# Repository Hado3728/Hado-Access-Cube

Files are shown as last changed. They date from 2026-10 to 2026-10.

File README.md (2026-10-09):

# HADO Edge Access Cube

A modular, 3D-printable enclosure and hardware architecture for a touchless, AI-powered access control terminal. Built for the IIITB-Qualcomm-Arduino COMET Hackathon.

\---

## Overview

The **HADO Edge Access Cube** combines dual-brain compute (Qualcomm QRB2210 Linux MPU + STM32U585 Real-Time MCU) with multi-modal sensing (MIPI Camera, Time-of-Flight depth sensing, and PN532 NFC) inside a compact $115 \\times 115 \\times 42\\text{ mm}$ 3-piece modular shell.

This repository contains the CAD models, AI prompt generation assets, bill of materials (BOM), and mechanical specifications required to manufacture, assemble, and deploy the physical device.

**WEBSITE
https://thunderous-marzipan-0d5d81.netlify.app/**
---

\---

## Mechanical Architecture

The enclosure uses a 3-piece snap-and-screw modular structure designed for FDM/SLA 3D printing and brass heat-set inserts.

```text
+-----------------------------------------------------------------+
| Part 1: Front Bezel \& Display Faceplate                         |
|   - Holds 4.3" COF Display, Camera, ToF Sensor, Mic, \& Speaker  |
+-----------------------------------------------------------------+
                                |  (Interlocking Lip + M2.5 Screws)
                                v
+-----------------------------------------------------------------+
| Part 2: Main Body Housing \& Chassis                             |
|   - Houses Qualcomm Arduino UNO Q MPU/MCU Stack \& NFC Rail      |
+-----------------------------------------------------------------+
                                |  (Flush Shoulder + M2.5 Screws)
                                v
+-----------------------------------------------------------------+
| Part 3: Rear Wall-Mounting Backplate                            |
|   - Features Keyhole Wall Mounts \& Cable Pass-Through Window    |
+-----------------------------------------------------------------+
```

### Key Enclosure Specs

* **Footprint:** $115\\text{ mm} \\times 115\\text{ mm} \\times 42\\text{ mm}$
* **Wall Thickness:** $2.5\\text{ mm}$ minimum structural wall thickness
* **Fasteners:** M2.5 and M3 brass heat-set inserts with countersunk machine screws
* **Materials Recommended:** PETG or ABS/ASA (25–30% Gyroid infill, 0.2mm layer height)

\---

## Hardware Stack \& Bill of Materials (BOM)

|Subsystem|Component|Interface / Notes|
|-|-|-|
|**Compute**|Qualcomm® Arduino® UNO™ Q|QRB2210 MPU + STM32U585 MCU|
|**Display**|Evelta 4.3" COF Non-Touch LCD (*DMG48270F043\_01WN*)|UART / TTL ($105.5 \\times 67.2 \\times 3.0\\text{ mm}$)|
|**Perception**|1080p MIPI-CSI RGB Camera Module|MIPI-CSI Ribbon Cable|
|**Depth / Proximity**|VL53L1X Time-of-Flight (ToF) Sensor|$\\text{I}^2\\text{C}$ Bus|
|**Contactless**|PN532 NFC Reader Board|$\\text{I}^2\\text{C}$ / SPI (Internal slide rail)|
|**Audio**|INMP441 MEMS Mic + 3W Speaker \& PAM8403 Amp|$\\text{I}^2\\text{S}$ \& PWM|
|**Power**|12V to 5V/3A DC-DC Buck Converter PMU|Terminal Block / USB-C|

\---

## Repository Structure

```text
├── cad/
│   ├── step/                 # STEP files for SolidWorks/Fusion 360 editing
│   ├── stl/                  # 3D printable STL files for slicers
│   └── prompts/              # Coordinate-mapped AI Text-to-CAD prompts (Parts 1-3)
├── docs/
│   ├── schematics/           # Wiring and interconnect diagrams
│   └── mechanics/            # Exploded assembly blueprints \& clearances
├── BOM                       # Complete hardware component list
├── LICENSE                   # MIT License
└── README.md                 # Project documentation
```

\---

## Assembly Instructions

1. **Insert Brass Heat-Sets:**

   * Press four **M2.5 brass heat-set inserts** into the corner bosses of **Part 1 (Front Bezel)** using a soldering iron.
   * Press four **M3 brass heat-set inserts** into the mainboard standoff pillars of **Part 2 (Main Housing)**.
2. **Mount Front Sensors \& Screen:**

   * Snap the Evelta 4.3" screen into the internal rear seat of Part 1.
   * Press-fit the MIPI camera and ToF sensor into their respective alignment sleeves.
3. **Install Core Compute \& NFC:**

   * Slide the PN532 NFC module into the top ceiling rail channel of Part 2 until the detent locks.
   * Secure the Qualcomm Arduino UNO Q board onto the M3 standoffs using M3x6mm screws.
4. **Final Closure:**

   * Join Part 1 and Part 2 via the perimeter interlocking lip.
   * Attach Part 3 to the rear shoulder and secure the entire sandwich using four M2.5x35mm countersunk machine screws driven from the backplate straight through to Part 1's brass inserts.

\---

## License

This project is open-source under the [MIT License](LICENSE).

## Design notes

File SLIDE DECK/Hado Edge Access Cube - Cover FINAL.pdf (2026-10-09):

I I I T B | • | Q U A L C O M M | • | A R D U I N O | C O M E T | H A C K A T H O N | — | P S # 0 6
C O N T A C T L E S S | A C C E S S | C O N T R O L

# HADO EDGE

# ACCESS CUBE

# How Dual-Brain Edge AI is Re-Engineering Access

Security.

FOOTPRINT

100 × 100 × 42 mm

PLATFORM

Qualcomm® /

Arduino® UNO™ Q

MODE

Face + Depth

fusion

I N T E R A C T I V E P R E S E N T A T I O N

# https: /hadoedgeaccesscube.netlif

# y.app/ (https://hadoedgeaccesscube.netlify.app/)

Click the link above to view the animated presentation in browser.

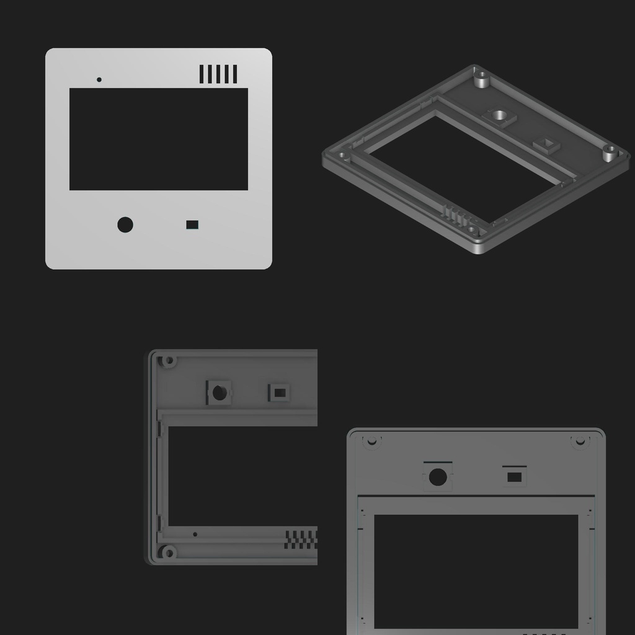
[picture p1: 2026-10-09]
SKETCHES/project_snapshot.jpeg

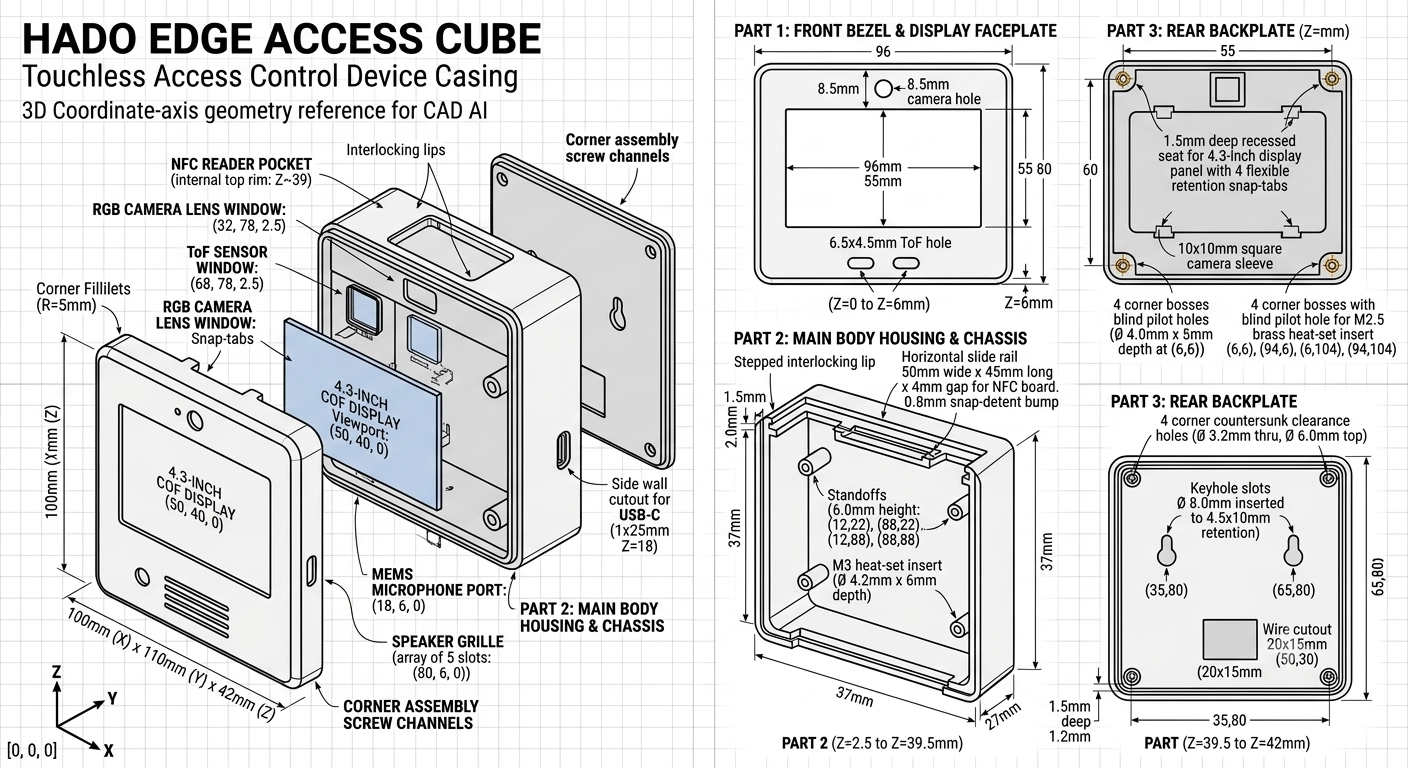
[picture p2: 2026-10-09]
SKETCHES/FULL SKETCH (NOT TO SCALE).png

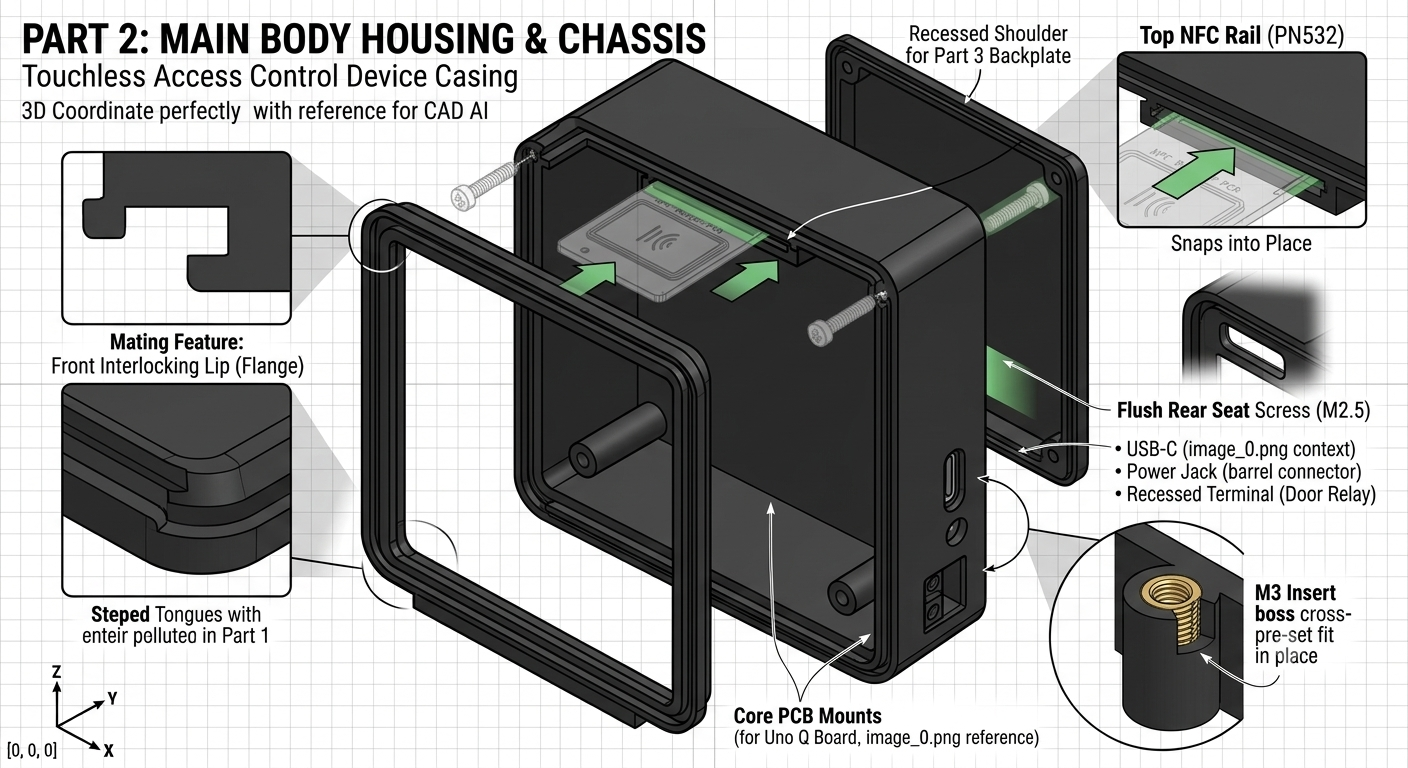
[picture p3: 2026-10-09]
SKETCHES/Part 2.png

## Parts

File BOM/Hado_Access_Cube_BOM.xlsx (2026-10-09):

Subsystem | Component | Specification / Part Number | Qty | Reference Link
Compute | Qualcomm® Arduino® UNO™ Q | QRB2210 MPU + STM32U585 MCU | 1 | https://www.arduino.cc/pro/
Display | Evelta 4.3" COF LCD | DMG48270F043_01WN (Non-Touch, TTL/UART) | 1 | https://www.evelta.com/4-3-inch-480x272-tft-lcd-display-module-ttl-uart-interface-dmg48270f043-01wn/
Perception | 1080p MIPI-CSI RGB Camera | Standard MIPI-CSI Ribbon Interface | 1 | https://www.sparkfun.com/search/results?term=mipi+camera
Depth | VL53L1X ToF Sensor | I2C Interface (STMicroelectronics) | 1 | https://www.adafruit.com/product/3967
Contactless | PN532 NFC Reader Board | I2C/SPI Interface | 1 | https://www.adafruit.com/product/364
Audio | INMP441 MEMS Mic | I2S Interface Omnidirectional | 1 | https://www.makerfabs.com/inmp441-omnidirectional-microphone-module.html
Audio | 3W Speaker + PAM8403 Amp | PWM / Class-D Audio Amplifier | 1 | https://www.adafruit.com/product/3366
Power | DC-DC Buck Converter PMU | 12V to 5V/3A (e.g., LM2596) | 1 | https://www.amazon.com/s?k=lm2596+buck+converter
Mechanical | M2.5 Brass Heat-Set Inserts | OD 4.0mm, Length 5.0mm | 8 | https://www.mcmaster.com/heat-set-inserts/
Mechanical | M3 Brass Heat-Set Inserts | OD 4.2mm, Length 6.0mm | 4 | https://www.mcmaster.com/heat-set-inserts/
Mechanical | M2.5 x 35mm Machine Screws | Countersunk (For Enclosure Assembly) | 4 | https://www.mcmaster.com/screws/
Mechanical | M3 x 6mm Machine Screws | Button Head (For Mainboard Mount) | 4 | https://www.mcmaster.com/screws/
Material | PETG or ABS/ASA Filament | 1.75mm, ~200g required | 1 | https://prusa3d.com/category/petg/

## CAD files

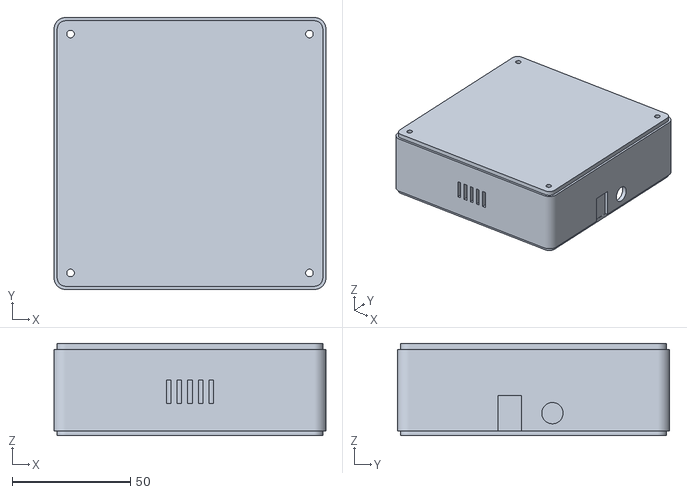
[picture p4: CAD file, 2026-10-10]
CAD FILES/part2_main_body.stl
115.0 x 115.0 x 39.0

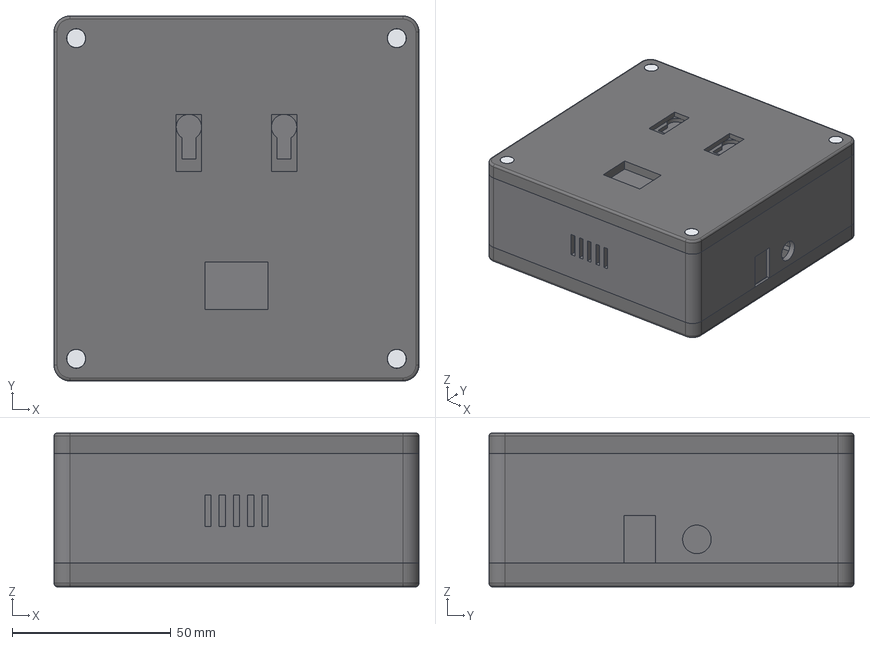
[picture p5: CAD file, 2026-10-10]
CAD FILES/assembly.step
115.0 x 115.0 x 48.5 mm
part1_front_bezel
part2_main_body
part3_rear_backplate
M2.5x45_1
M2.5x45_2
M2.5x45_3
M2.5x45_4

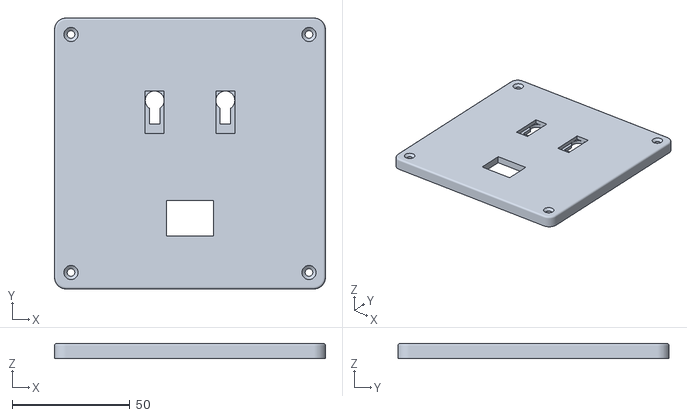
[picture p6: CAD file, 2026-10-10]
CAD FILES/part3_rear_backplate.stl
115.0 x 115.0 x 6.50

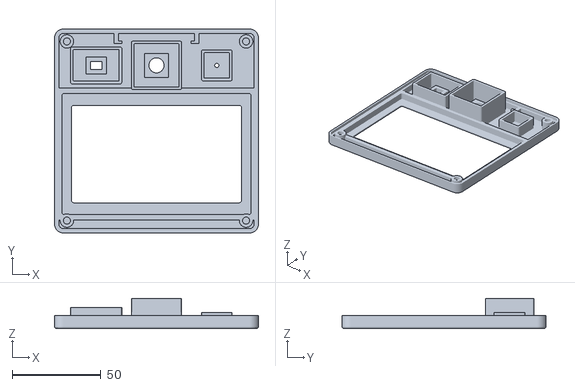
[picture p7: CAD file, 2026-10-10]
CAD FILES/part1_front_bezel.stl
115.0 x 115.0 x 17.0

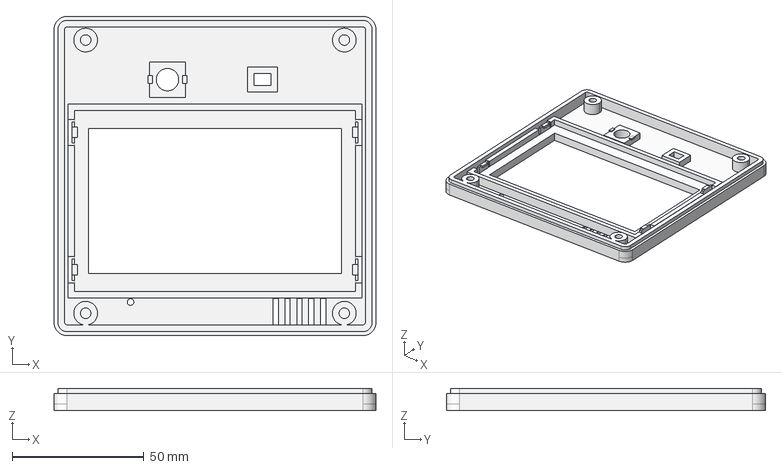
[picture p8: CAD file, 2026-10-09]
CAD FILES/Part1.step
122.0 x 121.0 x 8.50 mm

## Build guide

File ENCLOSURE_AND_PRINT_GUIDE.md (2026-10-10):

# Hado Edge Access Cube — Enclosure Design Basis, Component Register & Print Guide (Rev B)

CAD source: `cad/hado_cube.py` (CadQuery, parametric). Exports: `cad/export/*.step|*.stl`.
Frame: origin = centre of front face, **Z = 0 front → Z = 48.5 rear**, viewed from the front +X right, +Y up.

## 1. Component dimension register

Confidence: **A** = manufacturer document/product page, **B** = retailer listing of the exact part, **C** = typical value for the part class (pocket is oversized; **verify with calipers before printing**).

| Part (BOM) | Manufacturer | Dimensions used | Source / conf. |
|---|---|---|---|
| Arduino UNO Q (ABX00162) | Arduino | PCB 68.58 × 53.34 mm; holes Ø3.2 on UNO pattern (13.97,2.54) (15.24,50.8) (66.04,7.62) (66.04,35.56); headers ≈ 8.5 mm tall; underside parts < 2 mm | Arduino datasheet §12 (outline, 4×R1.6) **A**; hole coordinates = UNO form-factor pattern **A/inferred**; header height **C** |
| 4.3" COF LCD DMG48270F043_01WN | DWIN | Outline 105.52 × 67.17 × 3.0; active area 95.04 × 53.86 | Sister part DMG48270F043_02WN listing **B** (same family/outline; your memo agrees 105.5 × 67.2 × 3.0). `_01WN` datasheet drawing not retrievable — **verify AA offset on the FPC side** |
| VL53L1X breakout (Adafruit 3967) | Adafruit | 25.5 × 17.5 × 4.6 | Adafruit product page **A** |
| PN532 breakout (Adafruit 364) | Adafruit | **51 × 117.7 × 1.1 mm** | Adafruit product page **A** → *does not fit; see §2* |
| PN532 V3-class module (substitute) | Elechouse-pattern | 42.7 × 40.4 mm PCB, ≈ 4 mm with header | Retailer listings **B** |
| INMP441 module | module vendors (chip: TDK InvenSense) | Chip 4.72 × 3.76 × 1; module 14 × 14 × 3 | InvenSense datasheet **A** (chip); retailer **B** (module) |
| Mono amp (PAM8302 class) | Adafruit 2130 / PAM8302 | 24 × 15 (≈ 6 tall w/ trimpot, terminal) | Adafruit-class listing **B/C** |
| 3 W enclosed speaker | Adafruit 3351 | 70 × 30 × 17; Ø3.4 holes on 63 × 24 rectangle | Adafruit product page **A** |
| LM2596 buck module | generic | 43.2 × 21 × 14; Ø3 holes 6 mm from ends | Multiple retailer listings **B** |
| MIPI-CSI camera | *unspecified in BOM* | 25 × 24 × 9 pocket (Pi-camera-class) | **C — BOM has no part number** |
| DC jack, relay terminal | *not in BOM* | Ø9 hole; 15 × 10 window | From your memo |

## 2. Findings that changed the design (please read)

1. **Adafruit 364 PN532 is 117.7 mm long** — longer than the whole 115 mm enclosure. The design uses a 42.7 × 40.4 mm PN532 V3-class module instead. Change the BOM link accordingly. Note Adafruit lists I²C address **0x48** (shifted), not 0x24 as in the earlier wiring doc; most V3 modules use 0x24 — check your board.
2. **Depth 42 → 48.5 mm.** A 40.4 mm NFC board lying in the ceiling rail needs ≈ 41 mm of travel; 42 mm total depth leaves only ≈ 32 mm. Footprint stays 115 × 115.
3. **Speaker grille moved to the bottom wall.** The 70 × 30 × 17 speaker cannot sit on the front face (the strip below the display is 8 mm). It mounts on four M3 pads inside the bottom wall and radiates through five 2 × 10 mm slots. Your memo's front grille (y = 8 mm) also overlapped its own display seat.
4. **Display moved down** (centre y = −13 mm) so the camera / ToF / mic row sits above it with a ≥ 3 mm bridge, below the NFC rail.
5. **Screws are M2.5 × 45 mm** (not × 35): head seat to insert gives 45 mm. Inserts: pilot Ø4.0 × **5.5** mm (5.0 insert + 0.5 tip relief). Total M2.5 inserts needed: **4** (BOM lists 8).
6. **Power:** the UNO Q accepts **7–24 V on VIN** and 5 V on 5V_SYS (datasheet §3.1). The LM2596 is therefore optional for the UNO Q itself; it is kept for the display/amp 5 V rail as per BOM.
7. **Audio / camera interfaces:** the UNO Q exposes camera lanes only on the 60-pin **JMEDIA** connector (needs an adapter, a plain CSI ribbon will not plug in), and no I²S pins to the MCU; INMP441 needs a different route (USB audio, or the analog mic/line paths on JMISC). Verify before ordering.
8. **Not modelled / assumed:** display snap-tabs (retain with 1.0 mm VHB tape in the pocket), USB-C vertical position on the UNO Q (assumed centred on the short edge), sensor-chip position on the ToF and camera boards (assumed centred), mic-port offset. The official UNO Q STEP (`ABX00162-step.zip`, docs.arduino.cc) could not be downloaded here — drop it in `cad/ref/` and I'll align the cut-outs exactly.

## 3. Geometry summary

| Feature | Value |
|---|---|
| Envelope | 115 × 115 × 48.5; corner R5; walls ≥ 2.5 (≥ 2.5 everywhere except the 1.15 mm half-lap lands) |
| Part 1 (Z 0–7.5, sensor frames reach Z 17) | 1.0 skin; display pocket 106.5 × 68.2 × 3.2; window 96 × 55; camera Ø8.5 (13.5 sleeve), ToF 6.5 × 4.5 (11.5 × 9.5 sleeve), mic Ø2.4; 4 × M2.5 insert bosses |
| Part 2 (Z 5.5–44.5) | 2.5 floor; M3 standoffs 6.0 tall on UNO pattern; NFC ledge rail (channel 4.2 mm, 0.6 mm detent); USB-C 11 × 6, DC jack Ø9, relay window 15 × 10; speaker pads; LM2596 + amp cradles |
| Part 3 (Z 42–48.5) | 4.0 plate + 2.5 rim; 4 × countersunk Ø3.2 / Ø6.0; keyholes Ø8 + 4.5 × 10 with 2.2 rear recess; wire exit 20 × 15 |
| Half-lap joints | tongue 1.2 × 2.0, 0.15 mm clearance (front and rear) |

Fit check (script output): all components clear the shell (0 mm³) apart from the intentional 0.6 mm NFC detent bump; parts and screws do not interfere.

## 4. Print settings

| Setting | PETG (indoor) | ASA (warm/outdoor) |
|---|---|---|
| Nozzle / layer | 0.4 mm / **0.2 mm** | same |
| Perimeters | **6** (2.7 mm) | 6 |
| Top / bottom | 5 / 5 layers | 5 / 5 |
| Infill | **25–30 % gyroid** | same |
| Nozzle / bed | 235–245 °C / 70–80 °C | 250–260 °C / 100–110 °C, enclosed, fan off |
| Speed | 40 mm/s outer, 60 inner | same |
| Supports | none | none |
| Orientation | Part 1 front-face down · Part 2 floor down (open front up) · Part 3 plate down | same |

Orientation reasons: in these orientations the NFC rails, grille slots and side ports run along the print axis (no bridging), and the show face prints against the bed.

**Calibrate first:** print a 20 mm tall coupon of the tongue/groove and one M2.5 pilot. If the lap is tight, add 0.05 mm clearance per side; if the insert pilot is loose, drop to Ø3.9 mm.

## 5. Inserts, fasteners, assembly

| Item | Qty | Spec | Notes |
|---|---|---|---|
| M2.5 brass insert | 4 | OD 4.0 × 5.0, pilot Ø4.0 × 5.5 | Part 1 corner bosses, tip 220–240 °C (PETG) / 240–260 °C (ASA) |
| M3 brass insert | 4 (+4 for speaker) | OD 4.2 × 6.0 | Part 2 standoffs; speaker pads need M3 × 8 screws |
| M2.5 × 45 countersunk | 4 | 0.20–0.25 N·m | Part 3 → Part 1, through the corner channels |
| M3 × 6 button head | 4 | 0.30–0.40 N·m | UNO Q to standoffs |

1. Install inserts. 2. Slide the NFC module into the ledge rail from the front until it clicks over the detent. 3. Fit UNO Q, LM2596, amp, speaker. 4. Press the display into its pocket with VHB; fit camera / ToF / mic into their frames (a drop of CA glue at two corners). 5. Close Part 1 onto Part 2 (half-lap), seat Part 3, drive four screws in a cross pattern.

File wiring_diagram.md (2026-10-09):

# Hado Edge Access Cube — Electrical Architecture & Wiring

**Revision:** A · **Target:** IIITB-Qualcomm-Arduino COMET Hackathon · **Logic level:** 3.3 V throughout

> Items marked **[VERIFY]** depend on the exact UNO Q pin-mux / board revision. Confirm against the official UNO Q pinout before ordering a harness.

## 1. System Overview

```
12 V DC jack ─► PTC 3 A ─► Buck 12→5 V / 3 A ─┬─► UNO Q (5 V in) ─► on-board 3V3 rail ─┬─► VL53L1X
                                              ├─► 4.3" LCD (5 V)                      ├─► PN532 (I2C)
                                              ├─► PAM8403 (5 V) ─► 3 W speaker         └─► INMP441
                                              └─► MIPI-CSI camera (via UNO Q connector)
```

| Block | Part | Role |
|---|---|---|
| Compute | Arduino UNO Q (QRB2210 MPU + STM32U585 MCU) | MPU: vision / UI / network. MCU: real-time I/O (NFC, ToF, relay) |
| Display | Evelta 4.3" COF, DMG48270F043_01WN | UART/TTL command display, non-touch |
| Vision | MIPI-CSI 1080p RGB camera | Face / presence capture on the MPU |
| Range | VL53L1X ToF | Wake-on-approach, distance gating |
| Contactless | PN532 | 13.56 MHz credential read, top rail |
| Audio | INMP441 + PAM8403 + 3 W speaker | Voice capture + feedback tones |

## 2. Power Distribution

| Rail | Source | Loads | Est. peak |
|---|---|---|---|
| 12 V | Barrel jack (5.5/2.1 mm), PTC 3 A, SS34 reverse diode | Buck input; door-relay coil (external) | — |
| 5 V | Buck module, 3 A | UNO Q, LCD, PAM8403, camera | ≈ 2.3 A |
| 3V3 | UNO Q on-board regulator | VL53L1X, PN532 logic, INMP441 | ≈ 0.25 A |

Budget (design estimates, measure on bench): UNO Q ≈ 1.0 A, LCD ≈ 0.35 A, camera ≈ 0.25 A, PN532 ≈ 0.15 A, PAM8403 at 3 W ≈ 0.55 A → **≈ 2.3 A, ~25 % headroom**.

- Star-ground at the buck output. Add **470 µF** bulk + **100 nF** at the PAM8403 supply pins, **220 µF** at the LCD.
- Set the buck to **5.10 V** under load; verify before connecting the UNO Q.
- Feed the UNO Q through the supply input specified in its datasheet **[VERIFY]**; never back-feed from USB-C while the buck is live.
- Door relay switches on an **external** 12 V line via the recessed terminal block; keep it galvanically separate from logic ground (opto-isolated relay module recommended).

## 3. Bus Allocation

### 3.1 I²C (single bus, 400 kHz)

| Device | Address | Notes |
|---|---|---|
| VL53L1X | `0x29` | XSHUT on D4 for boot-time address control |
| PN532 | `0x24` | I²C mode: SEL0 = H, SEL1 = L (check board DIP/solder pads) |

- SDA/SCL on the UNO Q I²C header (A4/A5 / Qwiic) **[VERIFY]**. One set of **4.7 kΩ** pull-ups to 3V3 (disable duplicates on breakouts).
- PN532 `IRQ` → D2, `RSTPD_N` → D3. VL53L1X `GPIO1` → D5 (interrupt).
- Keep the PN532 cable ≤ 150 mm and routed away from the PAM8403 output pair.

### 3.2 UART / TTL (LCD bridge)

| UNO Q | LCD (DMG48270F043_01WN) | Notes |
|---|---|---|
| D1 (TX, MCU UART) | RX | 115200 8N1 default; 3.3 V logic |
| D0 (RX, MCU UART) | TX | |
| 5 V / GND | VCC / GND | Add 220 µF at the LCD connector |

### 3.3 I²S (INMP441)

| INMP441 | UNO Q | Notes |
|---|---|---|
| SCK (BCLK) | I²S/SAI BCLK pin **[VERIFY]** | |
| WS (LRCLK) | I²S/SAI WS pin **[VERIFY]** | |
| SD | I²S/SAI data-in **[VERIFY]** | |
| L/R | GND | Left-channel slot |
| VDD / GND | 3V3 / GND | Decouple 100 nF + 10 µF |

Mic port is a Ø2.4 mm acoustic hole in Part 1; keep the breakout ≤ 3 mm behind it, with a foam gasket.

### 3.4 Audio out

UNO Q **DAC pin (A0) [VERIFY]** → 10 µF + 10 kΩ divider → PAM8403 `L-IN` → 3 W / 4 Ω speaker. Tie `R-IN` to GND. Keep speaker leads twisted and short.

### 3.5 Camera

MIPI-CSI ribbon to the UNO Q camera connector **[VERIFY connector availability]**; if not exposed on your revision, substitute a USB UVC 1080p module (same 10×10 mm sleeve footprint).

## 4. Consolidated Pin Map

| Signal | UNO Q pin | Peer |
|---|---|---|
| I²C SDA / SCL | A4 / A5 **[VERIFY]** | VL53L1X, PN532 |
| LCD TX / RX | D1 / D0 | LCD RX / TX |
| PN532 IRQ / RST | D2 / D3 | PN532 |
| VL53L1X XSHUT / INT | D4 / D5 | VL53L1X |
| Relay drive | D6 | Opto relay IN |
| Tamper switch | D7 (INPUT_PULLUP) | Reed / microswitch to GND |
| I²S BCLK / WS / SD | **[VERIFY]** | INMP441 |
| DAC out | A0 **[VERIFY]** | PAM8403 L-IN |

## 5. Bring-up Checklist

1. Buck output at 5.10 V, no load. 2. Power UNO Q alone; confirm 3V3. 3. I²C scan shows `0x24`, `0x29`. 4. LCD echo test over UART. 5. Mic capture at 16 kHz; speaker tone sweep. 6. NFC read, then ToF-triggered wake. 7. Relay under load, with enclosure closed, 30 min thermal soak (buck case ≤ 70 °C).

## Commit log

2026-10-09 Initial upload
    [Part1.step]
2026-10-09 ADDED THE BOM FILE
    [Hado_Access_Cube_BOM.xlsx]
2026-10-10 CAD FILES COMPLETED AND COMMITING
    [assembly.step, part1_front_bezel.stl, part2_main_body.stl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]
